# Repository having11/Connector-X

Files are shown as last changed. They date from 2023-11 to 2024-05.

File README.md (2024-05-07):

# Connector-X

A drop-in, highly-configurable IO board compatible with the NI/FRC RoboRIO

- [Connector-X](#connector-x)
  - [The concept](#the-concept)
  - [Hardware features](#hardware-features)
  - [Attaching to your RIO](#attaching-to-your-rio)
  - [What are ports and zones?](#what-are-ports-and-zones)
  - [It can show images](#it-can-show-images)
  - [Command structure](#command-structure)
  - [Test sequences](#test-sequences)
  - [Expansion](#expansion)

## The concept

Have you ever wanted to leverage the power and extensibility of the Arduino ecosystem on other hardware but realized it's not supported? This was the case for FRC team 5690 SubZero Robotics in the 2023 season when we were attempting to add sensors and LEDs to our robot. Born from this struggle was a very simple Arduino Nano-based board that supported a single LED strip, limited LED patterns, and a duty-cycle output for lidar. As one might imagine, this was quite limited, so the 2023 off-season was spent designing and then redesigning a brand new system called the Connector-X (Connect Anything).

The new system is meant to be far faster and more flexible, as its Raspberry Pi Pico processor allows it to act as both a peripheral for a RoboRIO and a central device for connecting sensors.

## Hardware features

Starting along the top of the Connector-X is a pair of buttons that allow for reconfiguring the device and resetting it if needed. The DIP switch to the right was used to set the I2C address, but recent changes to the firmware have made it unnecessary. Lastly, the 3.3V regulator and Schottky diode help regulate incoming power and prevent damage if the inputs are accidentally reversed.

The DC barrel jack is meant for connecting 5V, center-positive power from a buck converter or other source that can supply a sufficient amount of current (> 5A preferred). Two LED ports sit below it, and each one has a starting, test WS2812B LED to help debug LED strip problems. The center has headers for 1 x SPI, 2 x I2C, and 3 x GPIO. Status indicators below the Pico display Power, Pico functionality, and I2C activity.

## Attaching to your RIO

At the bottom of the board is a male 2 x 17 header and a female 2 x 17 header, both of which conform to and pass-through the RIO's MXP connector standard. The Connector-X itself is only electrically connected to the I2C `SDA`, I2C `SCL`, and `GND` pins, meaning that a power issue on the board will not affect the RIO.

## What are ports and zones?

As mentioned before, the two ports each connect to a single LED strip, but that leads to the question of how different patterns can be easily shown on the same strip. So rather than connecting a strip per-port, the Connector-X allows for the strip to be subdivided into virtual zones that range from a single pixel all the way to the entire strip's length. To specify one, simply declare the offset (inclusive) and the size of the zone while ensuring it stays within the total number of LEDs present in the strip. The controlling device then sends commands to select the desired port and zone by index when setting colors/patterns.

## It can show images

Within the `Configuration`, either a `strip` or `matrix` configuration can be set. In the case of a `matrix`, the port is automatically split into two zones with the first being the single test LED and the second as the matrix itself. Currently, there are seven patterns that make use of the matrix, and they generally work by accessing images as follows:

1. A folder is created within the [data](./connector_x/data/) directory
2. 16-bit RGB bitmaps are placed into the folder. Names should be numeric, start at 0, and have the exact same number of images as the number of states specified in the [Pattern configuration](./connector_x/include/Patterns.h)
3. Selecting the pattern from a controlling device causes the Connector-X to cycle through them with the delay specified in the config or the command

## Command structure

Now that Commands have been mentioned several times, you're probably wondering what it actually _is_. A Command is simply a small amount of data that the controlling device sends to the Connector-X containing the `CommandType` and an arbitrary amount of additional data depending on what the `CommandType` equals.

| `CommandType` | Description | Additional data |
| :--- | :---: | :---: |
| On | Turns on an LED port | N/A |
| Off | Turns off an LED port | N/A |
| Pattern | Sets the current Pattern for a Zone | Pattern type, is one-shot, delay |
| ChangeColor | Sets the current Color for a Zone | R, G, B |
| ReadPatternDone | Checks if the set Pattern is done running | N/A |
| SetLedPort | Sets the active LED Port | Port number |
| DigitalSetup | Sets the mode (Read or Write) for a Digital IO Port | Port number, mode |
| DigitalWrite | Sets a Digital IO Port High or Low | Port number, value |
| DigitalRead | Reads a Digital IO Port's state | Port number |
| SetConfig (unused) | Sets a new Config for the Connector-X | N/A |
| RadioSend (unused) |  Sends data to other teams via the onboard Packet Radio when enabled  | N/A |
| RadioGetLatestReceived (unused) | Gets the latest Packet Radio data when enabled | N/A |
| GetColor | Gets the active Color for a Zone | N/A |
| GetPort | Gets the selected Port | N/A |
| SetPatternZone | Sets the current Zone for the current Port | Zone index, is reversed |
| SetNewZones (unused) | Configures new Zones for the current Port | Zone count, zone array |
| SyncStates | Sets the selected Zones' Patterns to the same State (animation frame) | Zone count, zone index array |

## Test sequences

It is possible to execute a series of commands upon startup without intervention from the controlling device. To do so, simply specify a list of `TestCommand`s in [`TestCommands.h`](./connector_x/include/TestCommands.h) that include the command type and any other required `commandData` within the `union`.

## Expansion

Feel free to add Commands and Patterns to expand the functionality of your Connector-X. Some ideas might include adding an I2C sensor and passing it through, controlling an LED, or displaying images on a screen via SPI.

V3 coming soon...

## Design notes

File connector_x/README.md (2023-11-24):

# Connector-X

## Upload

To upload:

1. Head to the Platformio tab on the left extension pane.
2. Hold down the `BOOTSEL` button on the Pico
3. While holding the `BOOTSEL` button, click the `RST` button on the PCB
4. Release the `RST` button and THEN the `BOOTSEL` button in that order
5. Take note of the drive identifier that pops up
6. Set the `upload_port` value to that drive in [the project config file](platformio.ini)
7. Click `pico > General > Upload` in the Platformio tab

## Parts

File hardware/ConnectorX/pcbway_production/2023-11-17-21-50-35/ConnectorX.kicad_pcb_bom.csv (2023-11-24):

designator | quantity | value | pack | mpn | mount_type
C1, C2 | 2 | 10uF | C_0603_1608Metric |  | smt
C3, C4 | 2 | 100nF | C_0603_1608Metric |  | smt
D1 | 1 | MBRD1060 | TO-252-2 |  | smt
D2 | 1 | PWR | LED_1206_3216Metric |  | smt
D3 | 1 | ALV | LED_1206_3216Metric |  | smt
D4 | 1 | I2C | LED_1206_3216Metric |  | smt
D5, D6 | 2 | WS2812B | LED_WS2812B_PLCC4_5.0x5.0mm_P3.2mm |  | smt
D7, D8 | 2 | D_Schottky | D_SMA |  | smt
D9 | 1 | CONFIG | LED_0805_2012Metric |  | smt
H1, H2, H3, H4 | 4 | MountingHole | MountingHole_3.2mm_M3_Pad_Via |  | tht
J1 | 1 | Barrel_Jack_Switch | BarrelJack_Horizontal |  | tht
J10 | 1 | I2C 1 | PinHeader_1x04_P2.54mm_Vertical |  | tht
J11 | 1 | SPI 0 | PinHeader_1x06_P2.54mm_Vertical |  | tht
J2, J3, J4 | 3 | Conn_01x03_Socket | PinHeader_1x03_P2.54mm_Horizontal |  | tht
J5, J6 | 2 | Conn_01x03_Socket | JST_VH_B3PS-VH_1x03_P3.96mm_Horizontal |  | tht
J7 | 1 | RIO side | PinSocket_2x17_P2.54mm_Vertical |  | tht
J8 | 1 | Top side | PinHeader_2x17_P2.54mm_Vertical |  | tht
J9 | 1 | I2C 0 | PinHeader_1x04_P2.54mm_Vertical |  | tht
Q1 | 1 | IRLML5203TRPBF | SOT-23 |  | smt
R1, R2, R4 | 3 | 220 | R_0603_1608Metric |  | smt
R3 | 1 | 470 | R_0603_1608Metric |  | smt
SW1 | 1 | RST | SW_SPST_PTS645 |  | smt
SW2 | 1 | CONFIG | SW_SPST_PTS645 |  | smt
SW3 | 1 | SW_DIP_x03 | SW_DIP_SPSTx03_Slide_6.7x9.18mm_W6.73mm_P2.54mm_LowProfile_JPin |  | smt
TP1, TP2, TP3 | 3 | TestPoint | TestPoint_Pad_D2.5mm |  | tht
U1 | 1 | NCP1117-3.3_SOT223 | SOT-223-3_TabPin2 |  | smt
U2 | 1 | RaspberryPi_Pico | RaspberryPi_Pico_Common |  | tht

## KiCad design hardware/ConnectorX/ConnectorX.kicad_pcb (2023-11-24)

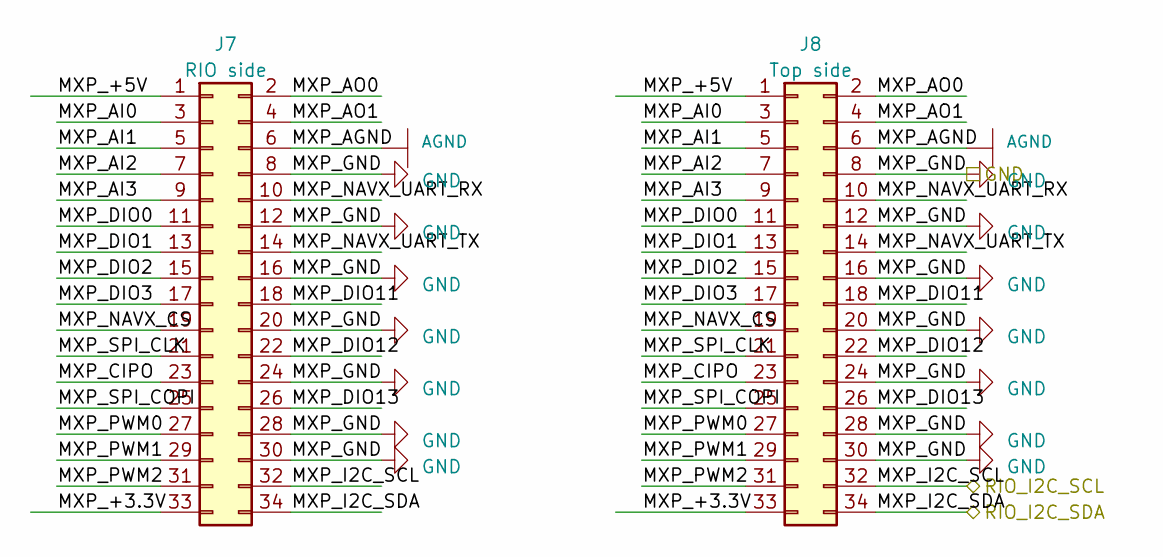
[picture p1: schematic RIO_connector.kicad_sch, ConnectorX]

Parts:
J7: RIO side; PinSocket_2x17_P2.54mm_Vertical
J8: Top side; PinHeader_2x17_P2.54mm_Vertical

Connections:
/I2C0_SCL: J7.32, J8.32; also elsewhere on the board
/MCU/I2C0_SDA: J7.34, J8.34; also elsewhere on the board
/RIO_connector/MXP_+3.3V: J7.33, J8.33
/RIO_connector/MXP_+5V: J7.1, J8.1
/RIO_connector/MXP_AI0: J7.3, J8.3
/RIO_connector/MXP_AI1: J7.5, J8.5
/RIO_connector/MXP_AI2: J7.7, J8.7
/RIO_connector/MXP_AI3: J7.9, J8.9
/RIO_connector/MXP_AO0: J7.2, J8.2
/RIO_connector/MXP_AO1: J7.4, J8.4
/RIO_connector/MXP_CIPO: J7.23, J8.23
/RIO_connector/MXP_DIO0: J7.11, J8.11
/RIO_connector/MXP_DIO1: J7.13, J8.13
/RIO_connector/MXP_DIO2: J7.15, J8.15
/RIO_connector/MXP_DIO3: J7.17, J8.17
/RIO_connector/MXP_DIO11: J7.18, J8.18
/RIO_connector/MXP_DIO12: J7.22, J8.22
/RIO_connector/MXP_DIO13: J7.26, J8.26
/RIO_connector/MXP_NAVX_CS: J7.19, J8.19
/RIO_connector/MXP_NAVX_UART_RX: J7.10, J8.10
/RIO_connector/MXP_NAVX_UART_TX: J7.14, J8.14
/RIO_connector/MXP_PWM0: J7.27, J8.27
/RIO_connector/MXP_PWM1: J7.29, J8.29
/RIO_connector/MXP_PWM2: J7.31, J8.31
/RIO_connector/MXP_SPI_CLK: J7.21, J8.21
/RIO_connector/MXP_SPI_COPI: J7.25, J8.25
AGND: J7.6, J8.6
GND: J7.8, J7.12, J7.16, J7.20, J7.24, J7.28, J7.30, J8.8, J8.12, J8.16, J8.20, J8.24, J8.28, J8.30; also elsewhere on the board

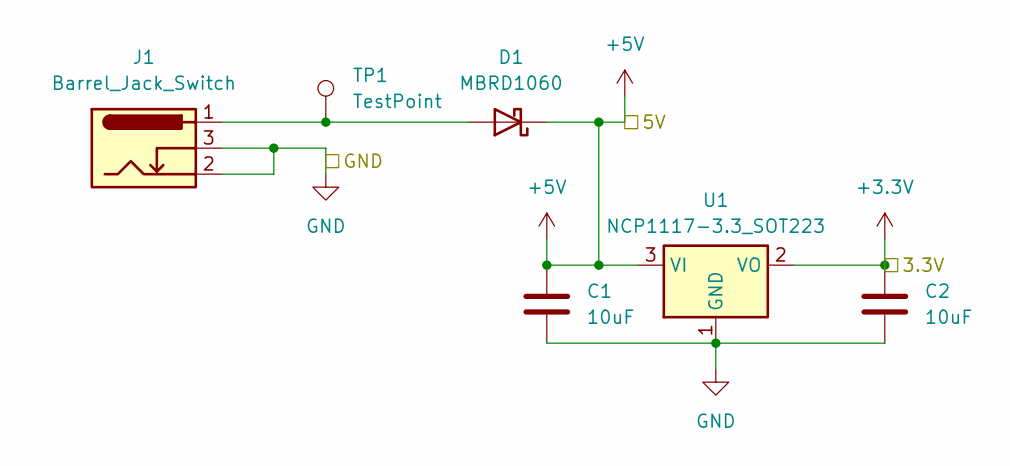
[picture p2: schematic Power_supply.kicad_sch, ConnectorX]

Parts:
C1, C2: 10uF; C_0603_1608Metric
D1: MBRD1060; TO-252-2
J1: Barrel_Jack_Switch; BarrelJack_Horizontal
TP1: TestPoint; TestPoint_Pad_D2.5mm
U1: NCP1117-3.3_SOT223; SOT-223-3_TabPin2

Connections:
+3.3V: C2.1, U1.2 (VO); also elsewhere on the board
+5V: C1.1, D1.1 (K), U1.3 (VI); also elsewhere on the board
GND: C1.2, C2.2, J1.2, J1.3, U1.1 (GND); also elsewhere on the board
unnamed: D1.2 (A), J1.1, TP1.1

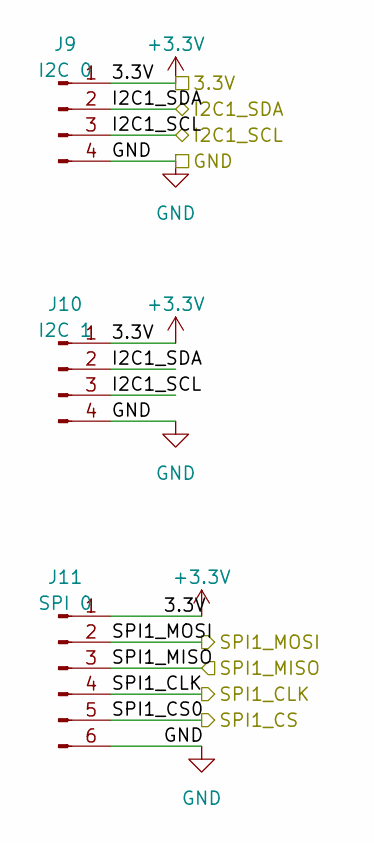
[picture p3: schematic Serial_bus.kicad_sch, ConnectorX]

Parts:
J9: I2C 0; PinHeader_1x04_P2.54mm_Vertical
J10: I2C 1; PinHeader_1x04_P2.54mm_Vertical
J11: SPI 0; PinHeader_1x06_P2.54mm_Vertical

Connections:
+3.3V: J9.1, J10.1, J11.1; also elsewhere on the board
/MCU/I2C1_SCL: J9.3, J10.3; also elsewhere on the board
/MCU/I2C1_SDA: J9.2, J10.2; also elsewhere on the board
/MCU/SPI1_CLK: J11.4; also elsewhere on the board
/MCU/SPI1_CS: J11.5; also elsewhere on the board
/MCU/SPI1_MISO: J11.3; also elsewhere on the board
/MCU/SPI1_MOSI: J11.2; also elsewhere on the board
GND: J9.4, J10.4, J11.6; also elsewhere on the board

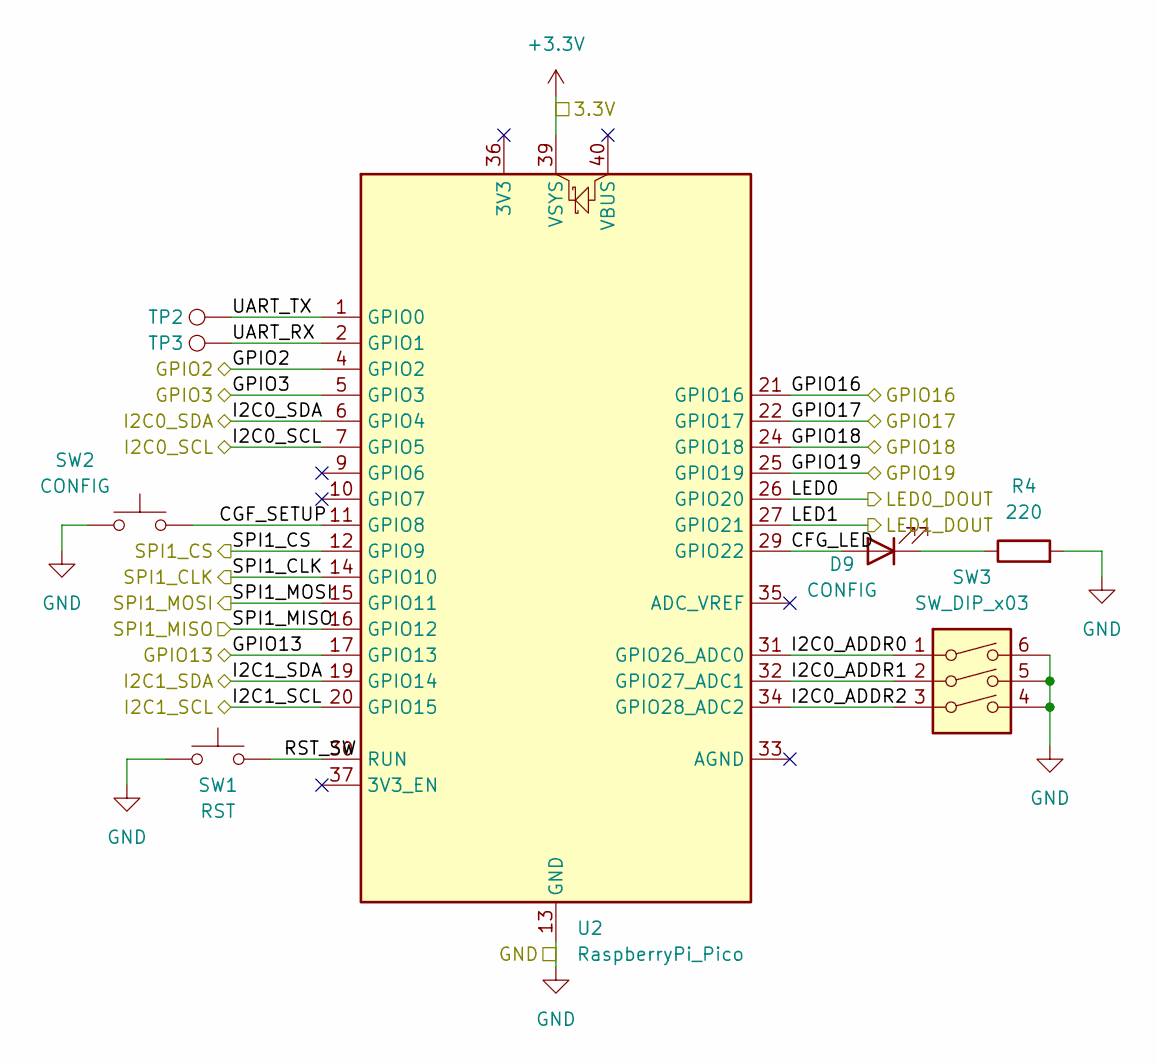
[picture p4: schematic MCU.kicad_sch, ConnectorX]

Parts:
D9: CONFIG; LED_0805_2012Metric
R4: 220; R_0603_1608Metric
SW1: RST; SW_SPST_PTS645
SW2: CONFIG; SW_SPST_PTS645
SW3: SW_DIP_x03; SW_DIP_SPSTx03_Slide_6.7x9.18mm_W6.73mm_P2.54mm_LowProfile_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
TP2, TP3: TestPoint; TestPoint_Pad_D2.5mm
U2: RaspberryPi_Pico; RaspberryPi_Pico_Common

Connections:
+3.3V: U2.39 (VSYS); also elsewhere on the board
/I2C0_SCL: U2.7 (GPIO5); also elsewhere on the board
/MCU/CFG_LED: D9.2 (A), U2.29 (GPIO22)
/MCU/CGF_SETUP: SW2.2, U2.11 (GPIO8)
/MCU/GPIO2: U2.4 (GPIO2); also elsewhere on the board
/MCU/GPIO3: U2.5 (GPIO3); also elsewhere on the board
/MCU/GPIO13: U2.17 (GPIO13)
/MCU/GPIO16: U2.21 (GPIO16); also elsewhere on the board
/MCU/GPIO17: U2.22 (GPIO17)
/MCU/GPIO18: U2.24 (GPIO18)
/MCU/I2C0_ADDR0: SW3.1, U2.31 (GPIO26_ADC0)
/MCU/I2C0_ADDR1: SW3.2, U2.32 (GPIO27_ADC1)
/MCU/I2C0_ADDR2: SW3.3, U2.34 (GPIO28_ADC2)
/MCU/I2C0_SDA: U2.6 (GPIO4); also elsewhere on the board
/MCU/I2C1_SCL: U2.20 (GPIO15); also elsewhere on the board
/MCU/I2C1_SDA: U2.19 (GPIO14); also elsewhere on the board
/MCU/LED0: U2.26 (GPIO20); also elsewhere on the board
/MCU/LED1: U2.27 (GPIO21); also elsewhere on the board
/MCU/RST_SW: SW1.2, U2.30 (RUN)
/MCU/SPI1_CLK: U2.14 (GPIO10); also elsewhere on the board
/MCU/SPI1_CS: U2.12 (GPIO9); also elsewhere on the board
/MCU/SPI1_MISO: U2.16 (GPIO12); also elsewhere on the board
/MCU/SPI1_MOSI: U2.15 (GPIO11); also elsewhere on the board
/MCU/UART_RX: TP3.1, U2.2 (GPIO1)
/MCU/UART_TX: TP2.1, U2.1 (GPIO0)
/PICO_ALV: U2.25 (GPIO19); also elsewhere on the board
GND: R4.2, SW1.1, SW2.1, SW3.4, SW3.5, SW3.6, U2.3 (GND), U2.8 (GND), U2.13 (GND), U2.18 (GND), U2.23 (GND), U2.28 (GND), U2.38 (GND); also elsewhere on the board
unnamed: D9.1 (K), R4.1

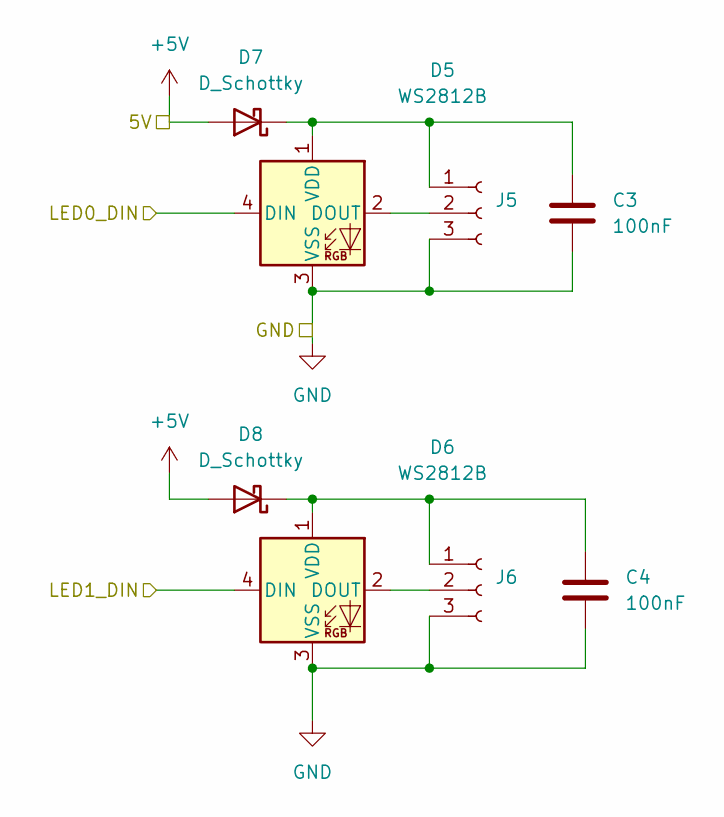
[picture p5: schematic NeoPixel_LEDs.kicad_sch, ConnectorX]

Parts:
C3, C4: 100nF; C_0603_1608Metric
D5, D6: WS2812B; LED_WS2812B_PLCC4_5.0x5.0mm_P3.2mm
D7, D8: D_Schottky; D_SMA
J5, J6: Conn_01x03_Socket; JST_VH_B3PS-VH_1x03_P3.96mm_Horizontal

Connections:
+5V: D7.2 (A), D8.2 (A); also elsewhere on the board
/MCU/LED0: D5.4 (DIN); also elsewhere on the board
/MCU/LED1: D6.4 (DIN); also elsewhere on the board
GND: C3.2, C4.2, D5.3 (VSS), D6.3 (VSS), J5.3, J6.3; also elsewhere on the board
unnamed: D5.2 (DOUT), J5.2
unnamed: C3.1, D5.1 (VDD), D7.1 (K), J5.1
unnamed: D6.2 (DOUT), J6.2
unnamed: C4.1, D6.1 (VDD), D8.1 (K), J6.1

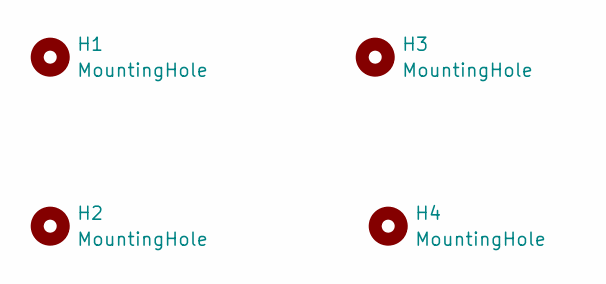
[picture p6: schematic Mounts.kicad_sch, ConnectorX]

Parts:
H1, H2, H3, H4: MountingHole; MountingHole_3.2mm_M3_Pad_Via

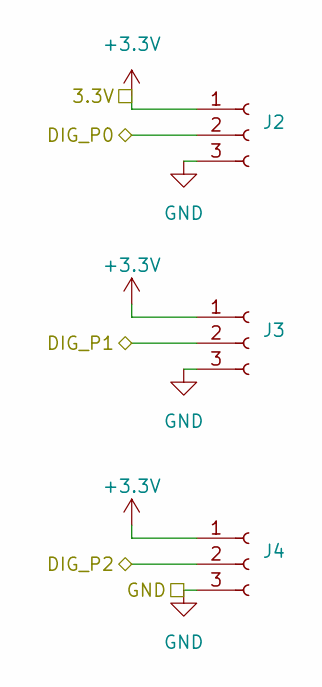
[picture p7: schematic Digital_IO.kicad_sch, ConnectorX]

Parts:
J2, J3, J4: Conn_01x03_Socket; PinHeader_1x03_P2.54mm_Horizontal

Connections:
+3.3V: J2.1, J3.1, J4.1; also elsewhere on the board
/MCU/GPIO2: J2.2; also elsewhere on the board
/MCU/GPIO3: J3.2; also elsewhere on the board
/MCU/GPIO16: J4.2; also elsewhere on the board
GND: J2.3, J3.3, J4.3; also elsewhere on the board

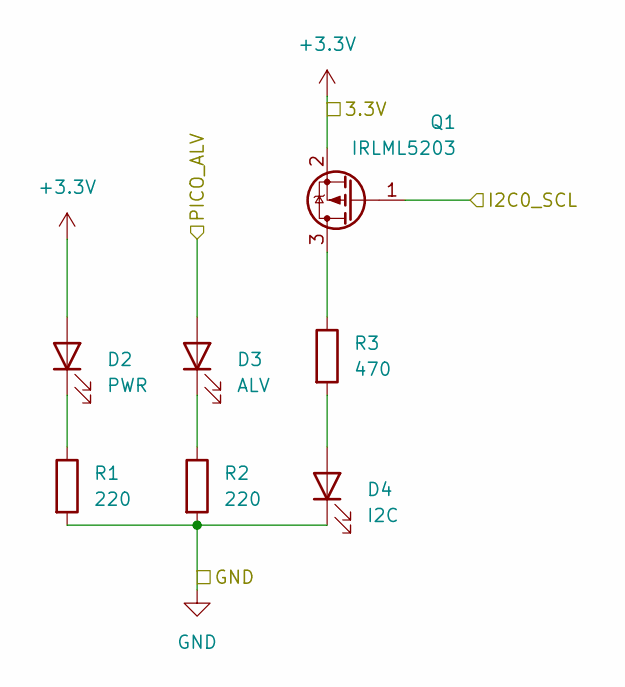
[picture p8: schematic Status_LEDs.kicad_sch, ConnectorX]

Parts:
D2: PWR; LED_1206_3216Metric
D3: ALV; LED_1206_3216Metric
D4: I2C; LED_1206_3216Metric
Q1: IRLML5203; SOT-23
R1, R2: 220; R_0603_1608Metric
R3: 470; R_0603_1608Metric

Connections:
+3.3V: D2.2 (A), Q1.2 (S); also elsewhere on the board
/I2C0_SCL: Q1.1 (G); also elsewhere on the board
/PICO_ALV: D3.2 (A); also elsewhere on the board
GND: D4.1 (K), R1.2, R2.2; also elsewhere on the board
unnamed: D2.1 (K), R1.1
unnamed: D3.1 (K), R2.1
unnamed: D4.2 (A), R3.2
unnamed: Q1.3 (D), R3.1

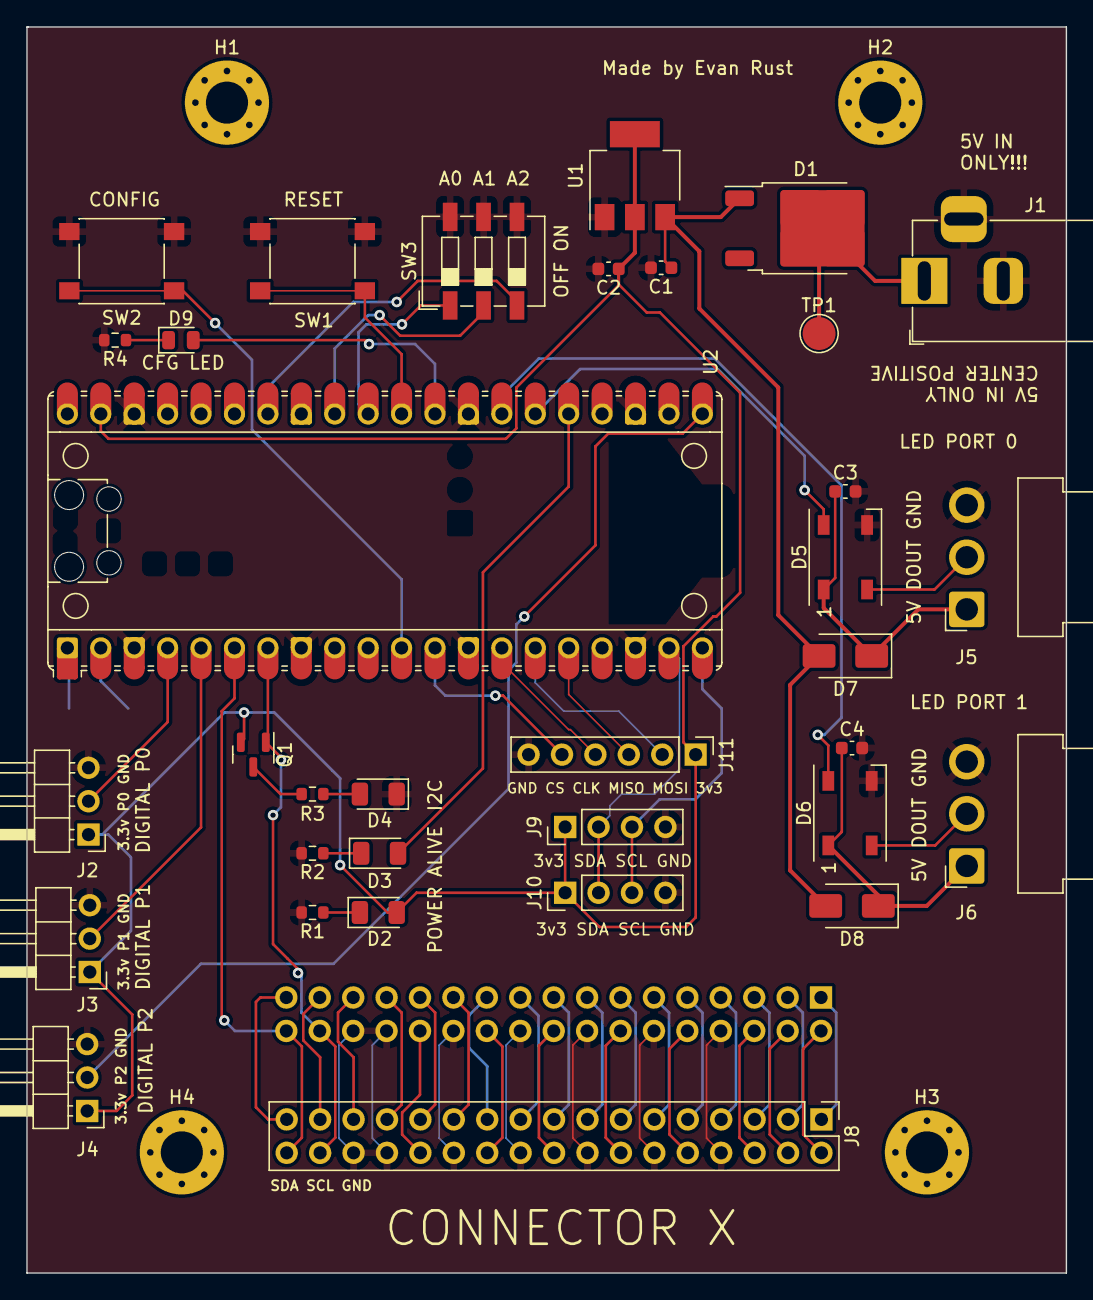
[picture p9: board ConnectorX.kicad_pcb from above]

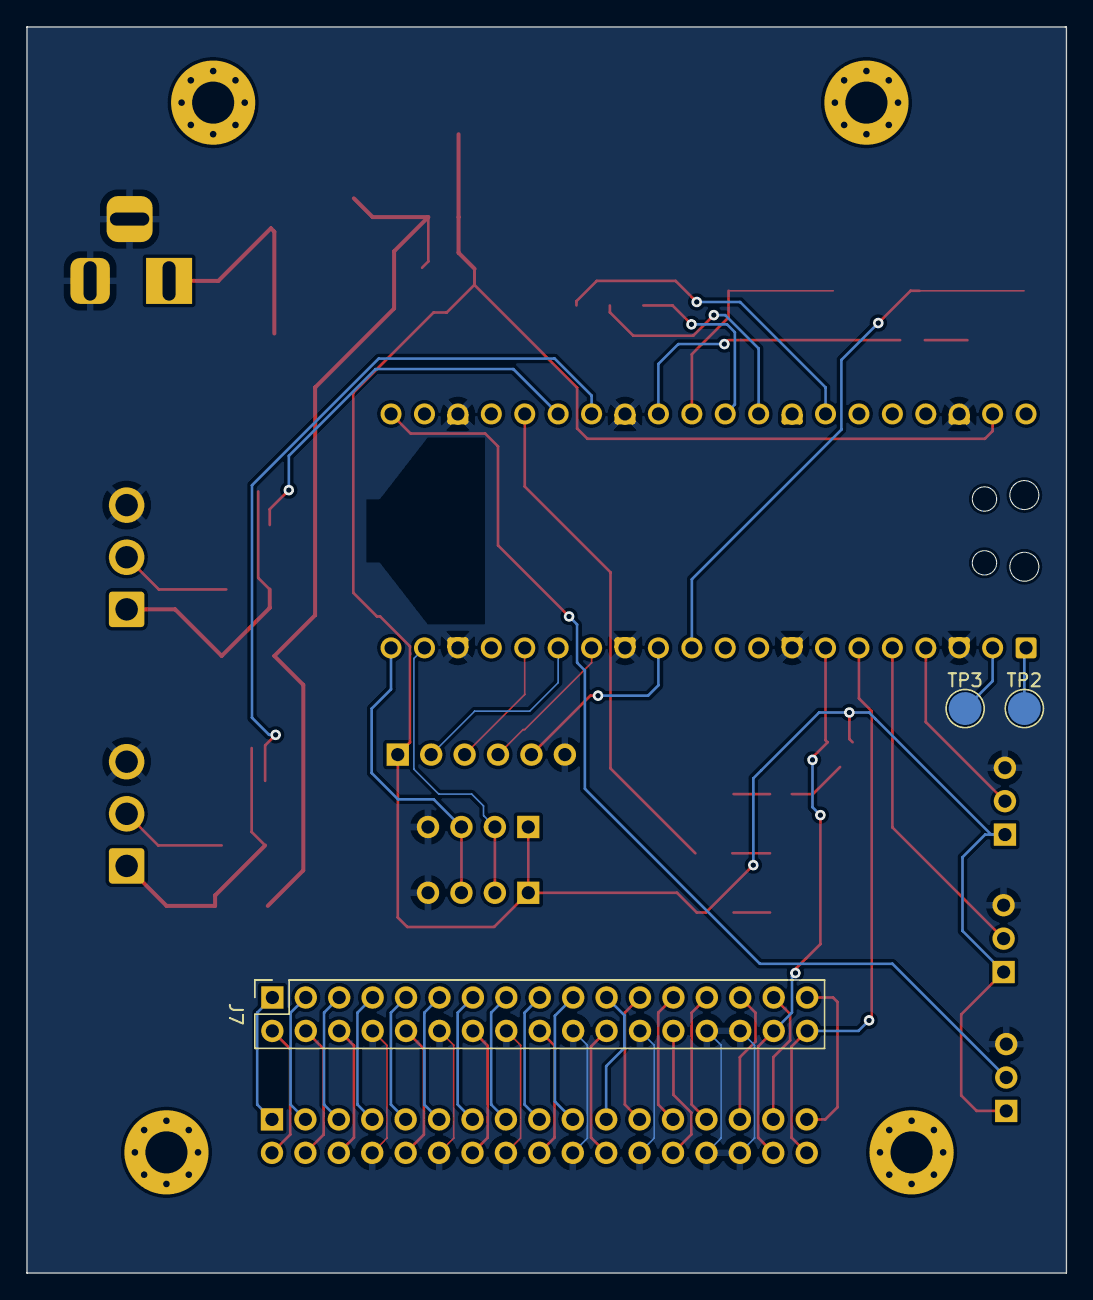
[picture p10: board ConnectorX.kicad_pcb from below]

Board: 2 copper layers, 79.0 x 94.7 mm, 41 parts (3 on the bottom side), 60 nets.

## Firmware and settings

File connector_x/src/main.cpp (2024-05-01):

#define PICO_USE_STACK_GUARDS 1

#include <Arduino.h>
#include <SD.h>
#include <SPI.h>
#include <Wire.h>

#include <pico/mutex.h>

#include <Adafruit_GFX.h>
#include <Adafruit_MPR121.h>
#include <FastLED_NeoMatrix.h>
#include <LittleFS.h>

#include "CommandParser.h"
#include "Commands.h"
#include "Configurator.h"
#include "Configuration.h"
#include "TestCommands.h"
#include "Constants.h"
#include "PacketRadio.h"
#include "PatternZone.h"
#include "SpectrumAnalyzer.h"

#include <memory>

// Uncomment to enable radio module communications
// #define ENABLE_RADIO
// Uncomment to enable OwO touch
// #define ENABLE_OWO

static mutex_t i2cCommandMtx;
static mutex_t radioDataMtx;
static mutex_t commandMtx;

// Give Core1 8K of stack space
bool core1_separate_stack = true;

// Forward declarations
void receiveEvent(int);
void requestEvent(void);
void handleRadioDataReceive(Message msg);
void centralRespond(Response response);
void initI2C0(void);
void initPixels(uint8_t port);
void handleCommand(Command cmd);

CRGB *getPixels(uint8_t port);

static volatile uint8_t receiveBuf[PinConstants::I2C::ReceiveBufSize];
static volatile bool newData = false;
static volatile bool newDataToParse = false;

static volatile uint8_t ledPort = 0;
static const std::vector<ZoneDefinition> defaultZoneDefs = {
    ZoneDefinition{0, 25},
    ZoneDefinition{25, 25},
    ZoneDefinition{50, 25},
    ZoneDefinition{75, 25},
};

static CRGB *pixels[PinConstants::LED::NumPorts];
static std::unique_ptr<PatternZone> zones[PinConstants::LED::NumPorts];

#ifdef ENABLE_RADIO
static PacketRadio *radio;
#endif

static Command command;
static CommandDeque commandDequeue;

#ifdef ENABLE_OWO
static Adafruit_MPR121 cap;

static volatile uint16_t curTouched = 0;
static volatile uint16_t lastTouched = 0;
#endif

static volatile bool systemOn = true;

void setup()
{
    rp2040.idleOtherCore();

    pinMode(PinConstants::LED::AliveStatus, OUTPUT);
    digitalWrite(PinConstants::LED::AliveStatus, HIGH);
    pinMode(PinConstants::CONFIG::ConfigSetupBtn, INPUT_PULLUP);
    pinMode(PinConstants::CONFIG::ConfigLed, OUTPUT);

    Wire1.setSDA(PinConstants::I2C::Port1::SDA);
    Wire1.setSCL(PinConstants::I2C::Port1::SCL);
    Wire1.begin();

    // EEPROM.begin(PinConstants::CONFIG::EepromSize);

    Serial.begin(UartBaudRate);

    rp2040.idleOtherCore();
    // config = configurator.begin();

    // Peripherals
    delay(3000);
    initI2C0();
    // Serial.println("I20 init done");

    SPI1.setTX(PinConstants::SPI::MOSI);
    SPI1.setRX(PinConstants::SPI::MISO);
    SPI1.setSCK(PinConstants::SPI::CLK);
    SPI1.setCS(PinConstants::SPI::CS0);
    SPI1.begin();

    Serial1.setTX(PinConstants::UART::TX);
    Serial1.setRX(PinConstants::UART::RX);
    Serial1.begin(UartBaudRate);

    mutex_init(&i2cCommandMtx);
    mutex_init(&radioDataMtx);
    mutex_init(&commandMtx);
    mutex_init(&spectrumMtx);

    LittleFSConfig cfg;
    cfg.setAutoFormat(false);
    LittleFS.setConfig(cfg);

    LittleFS.begin();

    #ifdef ENABLE_OWO
    cap.begin(0x5A, &Wire1);
    #endif

    pinMode(PinConstants::SPI::CS0, OUTPUT);
    digitalWrite(PinConstants::SPI::CS0, HIGH);

    for (auto pin : PinConstants::DIGITALIO::digitalIOMap)
    {
        pinMode(pin.second, OUTPUT);
        digitalWrite(pin.second, LOW);
    }

    // Serial.println("Initializing pixels");
    // TODO: make into a loop
    initPixels(0);
    initPixels(1);

    rp2040.resumeOtherCore();


#ifdef ENABLE_RADIO
    radio = new PacketRadio(&SPI1, config, handleRadioDataReceive);

    for (int i = 0; i < 2; i++)
    {
        radio->addTeam(config.initialTeams[i]);
    }
#endif

    // Serial.printf("Got config:\r\n%s\r\n",
    //               Configurator::toString(config).c_str());

    delay(2000);
    // Serial.println("Starting test sequence");
    digitalWrite(PinConstants::CONFIG::ConfigLed, HIGH);

    for (auto testCmd : testCommands) {
        Serial.printf("Handling %d\n", (uint8_t)testCmd.cmd.commandType);
        handleCommand(testCmd.cmd);
    }

    digitalWrite(PinConstants::CONFIG::ConfigLed, LOW);

    // spectrum.init();

    rp2040.resumeOtherCore();
    rp2040.restartCore1();

    // spectrum.startSampling();
}

void setup1()
{
    delay(2000);
    Serial.println("Setup1 has ended");
}

void loop1()
{
    mutex_enter_blocking(&commandMtx);
    bool available = commandDequeue.nextCommandAvailable();
    mutex_exit(&commandMtx);

    if (available)
    {
        Command cmd{};
        // Serial.printf("fifo available\n");
        mutex_enter_blocking(&commandMtx);
        int remaining = commandDequeue.getNextCommand(&cmd);
        mutex_exit(&commandMtx);

        // Serial.printf("remaining = %d\n", remaining);
        // Serial.printf("cmd type = %d\n", (uint8_t)cmd.commandType);

        if (remaining == -1) {
            // Serial.printf("ERROR: no actual commands to process\n");
            return;
        }

        switch (cmd.commandType)
        {
            case CommandType::On:
            {
                // Serial.println("Switching to on");
                // Go back to running the current color and pattern
                for (int i = 0; i < PinConstants::LED::NumPorts; i++)
                {
                    zones[i]->reset();
                }
                systemOn = true;
                break;
            }

            case CommandType::Off:
            {
                // Serial.println("Switching to off");
                // Set LEDs to black and stop running the pattern
                for (uint8_t port = 0; port < PinConstants::LED::NumPorts; port++)
                {
                    auto pixels = getPixels(ledPort);
                    Animation::executePatternSetAll(pixels, 0, 0, FastLED[port].size());
                    FastLED[port].showLeds();
                }
                systemOn = false;
                break;
            }

            case CommandType::Pattern:
            {
                // Serial.println("Pattern");
                // To set everything to a certain color, change color then call
                // the 'set all' pattern
                CommandPattern data = cmd.commandData.commandPattern;

                uint16_t delay =
                    data.delay == -1
                        ? zones[ledPort]->getPattern(data.pattern)
                            ->changeDelayDefault
                        : data.delay;

                zones[ledPort]->setPattern(data.pattern,
                                        delay,
                                        data.oneShot);
                break;
            }

            case CommandType::ChangeColor:
            {
                CommandColor data = cmd.commandData.commandColor;

                // Serial.printf("Color=%d|%d|%d\n", data.red, data.green, data.blue);

                // Handle port 0 being RGB instead of GRB
                if (ledPort == 0)
                {
                    uint8_t temp = data.red;
                    data.red = data.green;
                    data.green = temp;
                }

                zones[ledPort]->setColor(
                    (uint32_t)CRGB(data.red, data.green, data.blue));
                break;
            }

            case CommandType::SetLedPort:
            {
                ledPort = cmd.commandData.commandSetLedPort.port;
                // Serial.printf("Port=%d\n", ledPort);
                break;
            }

            case CommandType::SetPatternZone:
            {
                CommandSetPatternZone data = cmd.commandData.commandSetPatternZone;

                zones[ledPort]->setRunZone(data.zoneIndex, data.reversed);
                // Serial.printf("Pattern zone index=%u, reversed=%d\r\n",
                //     data.zoneIndex, data.reversed);
                break;
            }

            case CommandType::SetNewZones:
            {
                CommandSetNewZones data = cmd.commandData.commandSetNewZones;
                auto* zoneDefs = new std::vector<ZoneDefinition>();

                // Serial.printf("Seting up %d new zones\r\n", data.zoneCount);

                for (uint8_t i = 0; i < data.zoneCount; i++)
                {
                    zoneDefs->push_back(ZoneDefinition(data.zones[i].offset, data.zones[i].count));
                    // Serial.printf("Zone: %s\r\n", zoneDefs->at(i).toString().c_str());
                }

                auto& ledConfig = ledPort == 0 ? configuration.led0 : configuration.led1;

                zones[ledPort] = std::make_unique<PatternZone>(
                    ledPort, ledConfig.brightness, pixels[ledPort], zoneDefs);

                // Serial.printf("Set %d new zones\r\n", data.zoneCount);

                break;
            }

            case CommandType::SyncStates:
            {
                CommandSyncZoneStates data = cmd.commandData.commandSyncZoneStates;

                zones[ledPort]->resetZones(data.zones, data.zoneCount);
        // Serial.print(F("ON="));
        // Serial.println(systemOn);
            }
        }
    }

    if (systemOn)
    {
        // zones[1]->updateZones();
        for (int i = 0; i < PinConstants::LED::NumPorts; i++)
        {
            zones[i]->updateZones();
        }
    }
}

CRGB *getPixels(uint8_t port)
{
    if (port < PinConstants::LED::NumPorts)
    {
        return pixels[port];
    }

    return pixels[PinConstants::LED::DefaultPort];
}

void loop()
{
    // mutex_enter_blocking(&spectrumMtx);
    // spectrum.update();
    // mutex_exit(&spectrumMtx);

    // If there's new data, process it
    if (newDataToParse)
    {
        uint8_t buf[PinConstants::I2C::ReceiveBufSize];
        // Copy our new data
        mutex_enter_blocking(&i2cCommandMtx);
        memcpy(buf, (const void *)receiveBuf, PinConstants::I2C::ReceiveBufSize);
        mutex_exit(&i2cCommandMtx);
        // Serial.printf("Rec data buffer=\t");
        // for (int i = 0; i < 16; i++)
        // {
        //     Serial.printf("%X ", receiveBuf[i]);
        // }
        // Serial.println();
        Command cmdTemp{};
        CommandParser::parseCommand(buf, PinConstants::I2C::ReceiveBufSize, &cmdTemp);

        command = cmdTemp;

        newDataToParse = false;
        newData = false;
        // Serial.printf("Command struct=\t");
        // for (int i = 0; i < sizeof(command); i++)
        // {
        //     Serial.printf("%X ", ((uint8_t *)&command)[i]);
        // }
        // Serial.println();
        handleCommand(cmdTemp);
    }

    #ifdef ENABLE_OWO
    curTouched = cap.touched();

    if ((curTouched & 1 << 0) && !(lastTouched & 1 << 0)) {
        Command owoCmd = {
            .commandType = CommandType::SetLedPort,
            .commandData = {
                .commandSetLedPort = {
                    .port = 1,
                },
            },
        };
        
        handleCommand(owoCmd);

        owoCmd = {
            .commandType = CommandType::SetPatternZone,
            .commandData = {
                .commandSetPatternZone = {
                    .zoneIndex = 1,
                    .reversed = 0,
                },
            },
        };

        handleCommand(owoCmd);
        
        owoCmd = {
            .commandType = CommandType::Pattern,
            .commandData = {
                .commandPattern = {
                    .pattern = 14,
                    .oneShot = 0,
                    .delay = 500,
                },
            },
        };

        handleCommand(owoCmd);
    }

    if (!(curTouched & 1 << 0) && (lastTouched & 1 << 0)) {
        Command owoCmd = {
            .commandType = CommandType::SetLedPort,
            .commandData = {
                .commandSetLedPort = {
                    .port = 1,
                },
            },
        };
        
        handleCommand(owoCmd);

        owoCmd = {
            .commandType = CommandType::SetPatternZone,
            .commandData = {
                .commandSetPatternZone = {
                    .zoneIndex = 1,
                    .reversed = 0,
                },
            },
        };

        handleCommand(owoCmd);
        
        owoCmd = {
            .commandType = CommandType::Pattern,
            .commandData = {
                .commandPattern = {
                    .pattern = 12,
                    .oneShot = 0,
                    .delay = -1,
                },
            },
        };

        handleCommand(owoCmd);
    }

    lastTouched = curTouched;
    #endif

#ifdef ENABLE_RADIO
    radio->update();
#endif
}

void handleRadioDataReceive(Message msg)
{
    mutex_enter_blocking(&radioDataMtx);
    // Serial.println("New data:");
    // Serial.printf("Team = %d\n", msg.teamNumber);
    // Serial.printf("Data len = %d\n", msg.len);
    // Serial.print("Data (HEX) = ");

    // for (uint8_t i = 0; i < msg.len; i++)
    // {
    //     Serial.printf("%02X ", msg.data[i]);
    // }

    // Serial.println();

    mutex_exit(&radioDataMtx);
}

void receiveEvent(int howMany)
{
    Wire.readBytes((uint8_t *)receiveBuf, howMany);
    newDataToParse = true;
}

void requestEvent()
{
    Response res{};
    res.commandType = command.commandType;
    // Serial.printf("Sending back command=%d\n", (uint8_t)res.commandType);

    switch (command.commandType)
    {
    /**
     * @brief Returns uint8_t
     *
     */
    case CommandType::ReadPatternDone:
    {
        // auto done = getPatternRunner(ledPort)->patternDone();
        res.responseData.responsePatternDone.done = false;
        break;
    }

    /**
     * @brief Returns uint8_t
     *
     */
    case CommandType::DigitalRead:
    {
        uint8_t value = digitalRead(PinConstants::DIGITALIO::digitalIOMap.at(
            command.commandData.commandDigitalRead.port));
        res.responseData.responseDigitalRead.value = value;
        break;
    }

#ifdef ENABLE_RADIO
    case CommandType::RadioGetLatestReceived:
    {
        mutex_enter_blocking(&radioDataMtx);
        auto msg = radio->getLastReceived();
        mutex_exit(&radioDataMtx);

        res.responseData.responseRadioLastReceived.msg = msg;
        break;
    }
#endif

    case CommandType::ReadConfig:
    {
        // res.responseData.responseReadConfiguration.config = configuration;
        break;
    }

    case CommandType::GetColor:
    {
        // auto runner = getPatternRunner(ledPort);
        // uint32_t msg = runner->getCurrentColor();

        res.responseData.responseReadColor.color = 0x00;
        break;
    }

    case CommandType::GetPort:
    {
        res.responseData.responseReadPort.port = ledPort;
        break;
    }

    default:
        // Send back 255 (-1 signed) to indicate bad/no data
        Wire.write(0xff);
        return;
    }

    centralRespond(res);
}

void centralRespond(Response response)
{
    uint16_t size;

    switch (response.commandType)
    {
    case CommandType::ReadPatternDone:
        size = sizeof(ResponsePatternDone);
        break;
    case CommandType::DigitalRead:
        size = sizeof(ResponseDigitalRead);
        break;
    case CommandType::RadioGetLatestReceived:
        size = sizeof(ResponseRadioLastReceived);
        break;
    case CommandType::ReadConfig:
        size = sizeof(ResponseReadConfiguration);
        break;
    case CommandType::GetColor:
        size = sizeof(ResponseReadColor);
        break;
    case CommandType::GetPort:
        size = sizeof(ResponseReadPort);
        break;
    default:
        size = 0;
    }

    Wire.write((uint8_t)response.commandType);
    Wire.write((uint8_t *)&response.responseData, size);
}

void initI2C0(void)
{
    // pinMode(PinConstants::I2C::Port0::AddrSwPin0, INPUT_PULLUP);
    // uint8_t addr0Val = digitalRead(PinConstants::I2C::Port0::AddrSwPin0) == HIGH ? 1 : 0;
    // pinMode(PinConstants::I2C::Port0::AddrSwPin1, INPUT_PULLUP);
    // uint8_t addr1Val = digitalRead(PinConstants::I2C::Port0::AddrSwPin1) == HIGH ? 1 : 0;
    // pinMode(PinConstants::I2C::Port0::AddrSwPin2, INPUT_PULLUP);
    // uint8_t addr2Val = digitalRead(PinConstants::I2C::Port0::AddrSwPin2) == HIGH ? 1 : 0;

    // uint8_t i2cAddress =
    //     PinConstants::I2C::Port0::BaseAddress |
    //     (addr2Val << 2) |
    //     (addr1Val << 1) |
    //     (addr0Val);

    // Serial.printf("I2C address DEC=%d\n", i2cAddress);

    Wire.setSDA(PinConstants::I2C::Port0::SDA);
    Wire.setSCL(PinConstants::I2C::Port0::SCL);
    Wire.onReceive(receiveEvent); // register events
    Wire.onRequest(requestEvent);
    // TODO:
    Wire.begin(0x17); // join i2c bus as slave
}

void initPixels(uint8_t port)
{
    // Serial.println("Pixel start");
    // auto* strip = new CRGB[config->count];

    uint16_t ledCount;
    auto* ledZones = new std::vector<ZoneDefinition>();
    LedConfiguration config;

    if (port == 0) {
        config = configuration.led0;
    } else {
        config = configuration.led1;
    }

    if (!config.isMatrix) {
        ledCount = config.strip.count;

        if (config.strip.zoneCount != -1) {
            for (uint8_t i = 0; i < config.strip.zoneCount; i++) {
                ledZones->push_back(config.strip.initialZones[i]);
            }
        } else {
            ledZones->push_back(ZoneDefinition{0, ledCount});
        }
    } else {
        ledCount = (config.matrix.width * config.matrix.height) + 1;

        ledZones->push_back(ZoneDefinition{0, 1});
        ledZones->push_back(ZoneDefinition{1, ledCount - 1});
    }

    auto* strip = new CRGB[ledCount];
    pixels[port] = strip;
    zones[port] = std::make_unique<PatternZone>(port, config.brightness, pixels[port], ledZones);

    if (port == 0)
    {
        FastLED.addLeds<WS2812, PinConstants::LED::Dout0, RGB>(pixels[port], ledCount);
    }
    else
    {
        FastLED.addLeds<WS2812, PinConstants::LED::Dout1, GRB>(pixels[port], ledCount);
    }

    // Serial.printf("zones size=%d\r\n", zones[port]->_zones->size());

    FastLED[port].clearLedData();
    pixels[port][0] = CRGB(255, 127, 31);
    FastLED[port].showLeds();
    delay(1000);
    // Initialize all LEDs to black
    Animation::executePatternSetAll(pixels[port], 0, 0, FastLED[port].size());
    FastLED[port].showLeds();
    // Serial.println("Pixel end");
}

void handleCommand(Command cmd)
{
    switch (cmd.commandType)
    {
    case CommandType::On:
    {
        mutex_enter_blocking(&commandMtx);
        commandDequeue.pushCommand(cmd);
        mutex_exit(&commandMtx);
        // Go back to running the current color and pattern
        break;
    }

    case CommandType::Off:
    {
        mutex_enter_blocking(&commandMtx);
        // Set LEDs to black and stop running the pattern
        commandDequeue.pushCommand(cmd);
        mutex_exit(&commandMtx);
        break;
    }

    case CommandType::Pattern:
    {
        mutex_enter_blocking(&commandMtx);
        // To set everything to a certain color, change color then call
        // the 'set all' pattern
        
        commandDequeue.pushCommand(cmd);
        mutex_exit(&commandMtx);
        break;
    }

    case CommandType::ChangeColor:
    {
        mutex_enter_blocking(&commandMtx);
        commandDequeue.pushCommand(cmd);
        mutex_exit(&commandMtx);
        break;
    }

    case CommandType::SetLedPort:
    {
        mutex_enter_blocking(&commandMtx);
        commandDequeue.pushCommand(cmd);
        mutex_exit(&commandMtx);
        break;
    }

    case CommandType::DigitalSetup:
    {
        auto cfg = cmd.commandData.commandDigitalSetup;
        auto pin = PinConstants::DIGITALIO::digitalIOMap.at(cfg.port);
        pinMode(pin, cfg.mode);
        break;
    }

    case CommandType::DigitalWrite:
    {
        auto cfg = cmd.commandData.commandDigitalWrite;
        auto pin = PinConstants::DIGITALIO::digitalIOMap.at(cfg.port);
        digitalWrite(pin, cfg.value);
        break;
    }

    case CommandType::SetConfig:
    {
        // config = command.commandData.commandSetConfig.config;
        // // Serial.println("Storing new config=");
        // // Serial.println(configurator.toString(config).c_str());
        // configurator.storeConfig(config);
        break;
    }

#ifdef ENABLE_RADIO
    case CommandType::RadioSend:
    {
        auto message = command.commandData.commandRadioSend.msg;
        if (message.teamNumber == Radio::SendToAll)
        {
            radio->sendToAll(message);
        }
        else
        {
            radio->send(message);
        }
    }
#endif

    case CommandType::SetPatternZone:
    {
        mutex_enter_blocking(&commandMtx);
        commandDequeue.pushCommand(cmd);
        mutex_exit(&commandMtx);
        break;
    }

    case CommandType::SetNewZones:
    {
        mutex_enter_blocking(&commandMtx);
        commandDequeue.pushCommand(cmd);
        mutex_exit(&commandMtx);
        break;
    }

    case CommandType::SyncStates:
    {
        mutex_enter_blocking(&commandMtx);
        commandDequeue.pushCommand(cmd);
        mutex_exit(&commandMtx);
        break;
    }

    default:
        break;
    }
}

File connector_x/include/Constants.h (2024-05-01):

#pragma once

#include <Arduino.h>
#include <RFM69.h>
#include <unordered_map>

namespace PinConstants
{
    namespace I2C
    {
        constexpr uint8_t ReceiveBufSize = 128u;
        namespace Port0
        {
            constexpr uint8_t BaseAddress = 0b0010000;

            constexpr uint8_t SDA = 4;
            constexpr uint8_t SCL = 5;
            constexpr uint8_t AddrSwPin0 = 26;
            constexpr uint8_t AddrSwPin1 = 27;
            constexpr uint8_t AddrSwPin2 = 28;
        } // namespace Port0

        namespace Port1
        {
            constexpr uint8_t SDA = 14;
            constexpr uint8_t SCL = 15;
        } // namespace Port1
    }     // namespace I2C

    namespace SPI
    {
        constexpr uint8_t MISO = 12;
        constexpr uint8_t MOSI = 11;
        constexpr uint8_t CLK = 10;
        constexpr uint8_t CS0 = 9;
    } // namespace SPI

    namespace UART
    {
        constexpr uint8_t TX = 0;
        constexpr uint8_t RX = 1;
    } // namespace UART

    namespace LED
    {
        constexpr uint8_t Dout0 = 20;
        constexpr uint8_t Dout1 = 21;
        constexpr uint8_t AliveStatus = 19;
        constexpr uint8_t NumPorts = 2;
        constexpr uint8_t DefaultPort = 0;
    } // namespace LED

    namespace DIGITALIO
    {
        constexpr uint8_t P0 = 2;
        constexpr uint8_t P1 = 3;
        constexpr uint8_t P2 = 16;

        static const std::unordered_map<uint8_t, uint8_t> digitalIOMap = {
            {0, P0}, {1, P1}, {2, P2}};
    } // namespace DIGITALIO

    namespace CONFIG
    {
        constexpr uint8_t ConfigSetupBtn = 8;
        constexpr uint8_t ConfigLed = 22;
        constexpr uint16_t EepromSize = 4096u;
    }
} // namespace Pin

namespace FFT
{
    constexpr uint8_t AdcPin = A0;  // Pin 26
    constexpr uint8_t CaptureChannel = 0;
    constexpr uint16_t SampleCount = 64;
    constexpr double SampleFrequencyHz = 50000;
    constexpr uint16_t ClockDivider = 960;  // 50kHz
}

namespace Radio
{
    // ! Change to match schematic
    constexpr uint8_t RadioCS = 13;
    constexpr uint8_t RadioInterrupt = 17;
    constexpr uint8_t MaxRadioAddresses = 254;
    constexpr uint8_t NetworkId = 0;
    constexpr uint8_t Frequency = RF69_915MHZ;
    constexpr uint8_t MaxDataLen = RF69_MAX_DATA_LEN;
    constexpr uint16_t SendToAll = 0xFFFF;
} // namespace Radio

constexpr uint32_t UartBaudRate = 115200;
constexpr uint8_t PatternCount = 15;

namespace Animation
{
    constexpr double sineRollWidth = 10;
    constexpr uint8_t sineRollStates = 60;
    constexpr uint8_t chaseWidth = 5;
    constexpr uint16_t chaseSpacing = 10;
    constexpr uint16_t chaseRepeatWidth = chaseWidth + chaseSpacing;
}

namespace Matrix
{
    constexpr uint8_t Width = 32;
    constexpr uint8_t Height = 8;
}

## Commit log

2023-11-24 Initial upload (#1)
    [ConnectorX-B_Cu.gbr, ConnectorX-B_Mask.gbr, ConnectorX-B_Paste.gbr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]
2024-01-13 Fix led 0 count prompt
    [Configurator.cpp]
2024-01-13 get current color (#2)
    * get current color
    * array fixes
    * remove un-needed mutex
    * add handler in centralRespond()
    * get port
    * add handler in centralRespond()
    * create structs for GetColor and GetPort
    * Add CommandParser
    * assign ledPort directly to res.responseData.responseReadPort.msg
    [Commands.h, Constants.h, main.cpp]
2024-01-14 comment out print
2024-05-01 Pattern Zones (#4)
    * start zones
    * min working
    * multizone
    * It works!
    * add set zones command (untested)
    * fully working
    * add chase and sine patterns working
    * finalize zone updates
    * add core idling
    * Only show LEDs when needed
    * Expand Core1 stack size
    * 4 zones by default
    * async commands
    * more fixes
    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
    [Configuration.h]
